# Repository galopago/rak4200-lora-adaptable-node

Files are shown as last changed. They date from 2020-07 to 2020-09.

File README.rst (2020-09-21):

=======================================================================================================================================
RAK4200 based LoRa node, with multiple expansion possibilities and designed to fit inside a generic 83x58x33mm waterproof enclosure box.
=======================================================================================================================================

LoRa node powered by AA batteries ready to install inside an easy to find waterproof enclosure.

Read this in other languages: `Español </docs/README.es.rst>`_

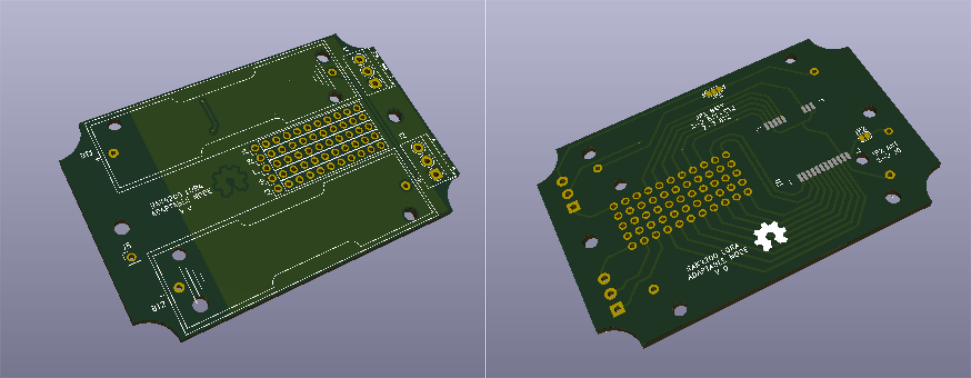
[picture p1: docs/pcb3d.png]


Key features:
-------------
* Powered by 2xAA (1.5v) batteries or a single (3.0v) battery.
* Waterproof if installed in an "easy to find worldwide" 83x58x33mm waterproof plastic enclosure (multiple choices: clear cover, wall mounting tabs, etc.).
* Class A battery powered or Class C external powered via screw terminal.
* RAK4200 = SX1276+STM32L071. So no additional cpu/microcontroller needed for a complete solution.
* Can be programmed using `RAK Unified Interface (RUI) API, <https://doc.rakwireless.com/quick-start/rak5010-wistrio-nb-iot-tracker/rui-online-compiler>`_ for rapid development or STM32 CUBE LoRa stack.
* TH pad for a spring antenna or U.FL connector for external antenna.
* Prototyping/expansion area.

How to use this repository
--------------------------

The PCB was developed in KiCad V5.1, and include some elements from the official repo.

To setup KiCad to use the downloaded library from the repo instead of the stock that came with the installer, `this post <https://forum.kicad.info/t/library-management-in-kicad-version-5/14636>`_ will give you some lights.

Directory structure
-------------------
* The root folder contains KiCad files: project, schematic and PCB.
* library directory (git submodule) contains schematics symbol libraries.
* modules directory (git submodule) contains footprint libraries.
* packages3d directory (git submodule) contains 3D model libraries.
* gerber/single directory contains ready to manufacture files, for a single board.
* gerber/panel_100mmx100mm directory contains ready to manufacture files that fits in a 100mm x 100mm panel (use Vcuts!).

License
-------



This is an Open Hardware project and is licensed under a `Creative Commons Attribution 4.0 International License, <http://creativecommons.org/licenses/by/4.0/>`_

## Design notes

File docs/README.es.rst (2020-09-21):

====================================================================================================================================================
Nodo LoRa basado en RAK4200, con multiples posibilidades de expansion y diseñado para instalarse en una caja a prueba de agua generica de  83x58x33mm 
====================================================================================================================================================

Nodo LoRa alimentado por baterias AA listo para instalar en caja a prueba de agua facil de conseguir.

Lea esto en otros idiomas: `English <../README.rst>`_



Caracteristicas claves:
-----------------------
* Alimentacion mediante 2 baterias AA (1.5v) o mediante una sola bateria de 3.0v en formato LR6.
* A prueba de agua si se instala en una caja plastica "facil de conseguir" de dimensiones 83x58x33mm. Hay varios modelos: tapa transparente, pestañas para montaje en pared, etc.).
* Clase A alimentado mediante baterias o clase C alimentado externamente por el terminal de tornillo.
* RAK4200 = SX1276+STM32L071. No se requiere una cpu o microcontrolador adicional para una solucion completa.
* Puede ser programado usando la API  `RAK Unified Interface (RUI), <https://doc.rakwireless.com/quick-start/rak5010-wistrio-nb-iot-tracker/rui-online-compiler>`_ para desarrollo rapido o mediante STM32 CUBE LoRa.
* Multiples posibilidades para antena: pad para soldar antena de resorte interna o conector U.FL para antena externa
* Area para prototipado y/o expansion.

Como usar este repositorio
--------------------------
El circuito impreso fue desarrollado en KiCad V5.1, e incluye algunos elementos de la biblioteca en el repositorio oficial.

Para configurar KiCad para que use las bibliotecas descargadas del repositorio en vez de usar las que vienen incluidas con el instalador, se recomienda leer el `siguiente articulo <https://forum.kicad.info/t/library-management-in-kicad-version-5/14636>`_ el cual brinda ideas de como hacerlo.

Estructura de directorios
-------------------
* El directorio raiz contiene los archivos de KiCad: proyecto, esquematico y circuito impreso.
* library (submodulo git) contiene las bibliotecas de simbolos esquematicos.
* modules (submodulo git) contiene las bibliotecas de footprints.
* packages3d (submodulo git) contiene las bibliotecas de modelos 3D.
* gerber/single contiene los archivos para fabricacion del circuito impreso, para una sola tarjeta.
* gerber/panel_100mmx100mm contiene los archivos para fabricacion del circuito impreso, para multiples tarjetas que caben en un panel de 100mm x 100mm (usando Vcuts!).

Licencia
-------



Este es un proyecto de Hardware Libre y esta licenciado bajo una licencia `Creative Commons Attribution 4.0 International License, <http://creativecommons.org/licenses/by/4.0/>`_

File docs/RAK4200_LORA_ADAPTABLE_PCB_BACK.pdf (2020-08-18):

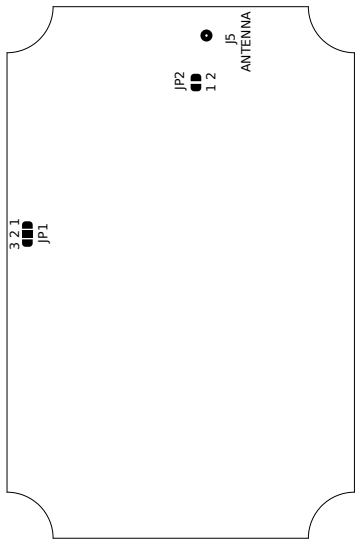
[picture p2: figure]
ANTENNA

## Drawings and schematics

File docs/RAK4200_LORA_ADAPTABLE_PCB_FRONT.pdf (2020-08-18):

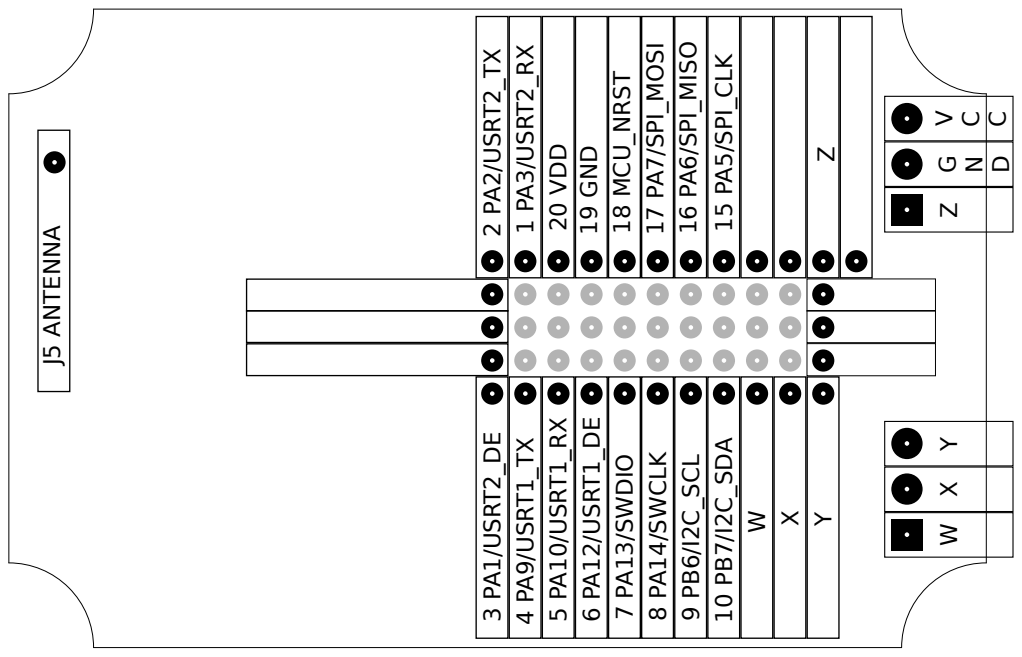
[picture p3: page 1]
3 PA1/USRT2_DE; 4 PA9/USRT1_TX; 5 PA10/USRT1_RX; 6 PA12/USRT1_DE; J5 ANTENNA; 7 PA13/SWDIO; 8 PA14/SWCLK; 9 PB6/I2C_SCL; 10 PB7/I2C_SDA; 2 PA2/USRT2_TX; 1 PA3/USRT2_RX; 20 VDD; 19 GND; 18 MCU_NRST; 17 PA7/SPI_MOSI; 16 PA6/SPI_MISO; 15 PA5/SPI_CLK; Z YXW

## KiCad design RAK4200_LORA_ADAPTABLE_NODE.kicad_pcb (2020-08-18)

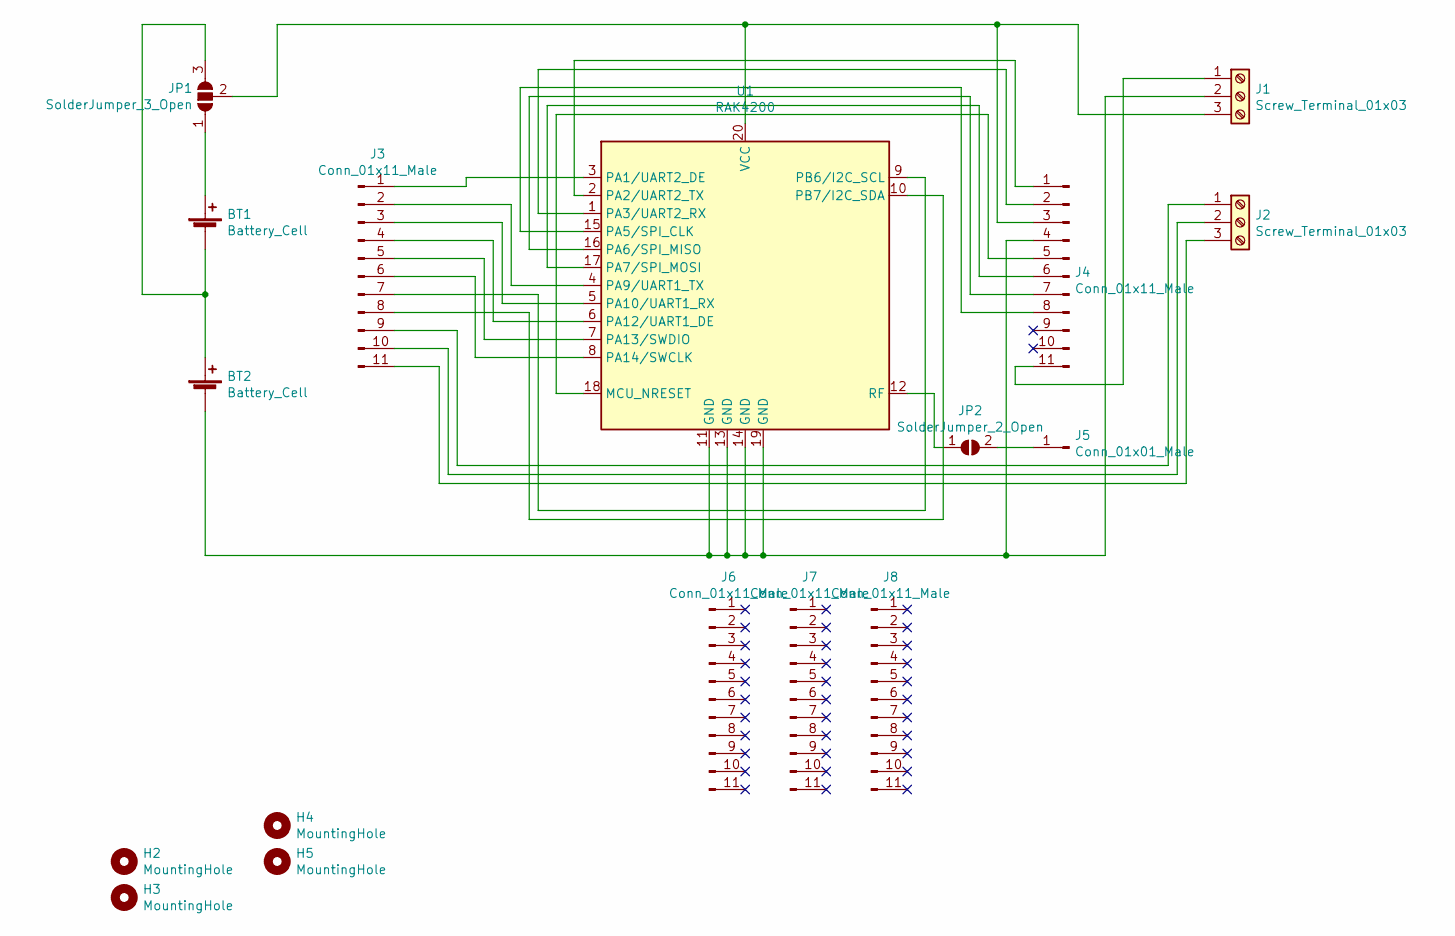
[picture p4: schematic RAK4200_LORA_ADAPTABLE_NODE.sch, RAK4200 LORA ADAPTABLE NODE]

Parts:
BT1, BT2: Battery_Cell; BatteryHolder_Keystone_2460_1xAA
H2, H3, H4, H5: MountingHole; MountingHole_3mm
J1, J2: Screw_Terminal_01x03; TerminalBlock_4Ucon_1x03_P3.50mm_Horizontal
J3, J4, J6, J7, J8: Conn_01x11_Male; PinHeader_1x11_P2.54mm_Vertical
J5: Conn_01x01_Male; PinHeader_1x01_P2.54mm_Vertical
JP1: SolderJumper_3_Open; SolderJumper-3_P1.3mm_Open_RoundedPad1.0x1.5mm_NumberLabels
JP2: SolderJumper_2_Open; SolderJumper-2_P1.3mm_Open_RoundedPad1.0x1.5mm
U1: RAK4200

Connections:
unnamed: BT1.1 (+), JP1.1 (A)
unnamed: BT1.2 (-), BT2.1 (+), JP1.3 (B)
unnamed: BT2.2 (-), J1.2, J4.4, U1.11 (GND), U1.13 (GND), U1.14 (GND), U1.19 (GND)
unnamed: J1.1, J4.11
unnamed: J1.3, J4.3, JP1.2 (C), U1.20 (VCC)
unnamed: J2.1, J3.9
unnamed: J2.2, J3.10
unnamed: J2.3, J3.11
unnamed: J3.1, U1.3 (PA1/UART2_DE)
unnamed: J3.2, U1.4 (PA9/UART1_TX)
unnamed: J3.3, U1.5 (PA10/UART1_RX)
unnamed: J3.4, U1.6 (PA12/UART1_DE)
unnamed: J3.5, U1.7 (PA13/SWDIO)
unnamed: J3.6, U1.8 (PA14/SWCLK)
unnamed: J3.7, U1.9 (PB6/I2C_SCL)
unnamed: J3.8, U1.10 (PB7/I2C_SDA)
unnamed: J4.1, U1.2 (PA2/UART2_TX)
unnamed: J4.2, U1.1 (PA3/UART2_RX)
unnamed: J4.5, U1.18 (MCU_NRESET)
unnamed: J4.6, U1.17 (PA7/SPI_MOSI)
unnamed: J4.7, U1.16 (PA6/SPI_MISO)
unnamed: J4.8, U1.15 (PA5/SPI_CLK)
unnamed: J5.1, JP2.2 (B)
unnamed: JP2.1 (A), U1.12 (RF)

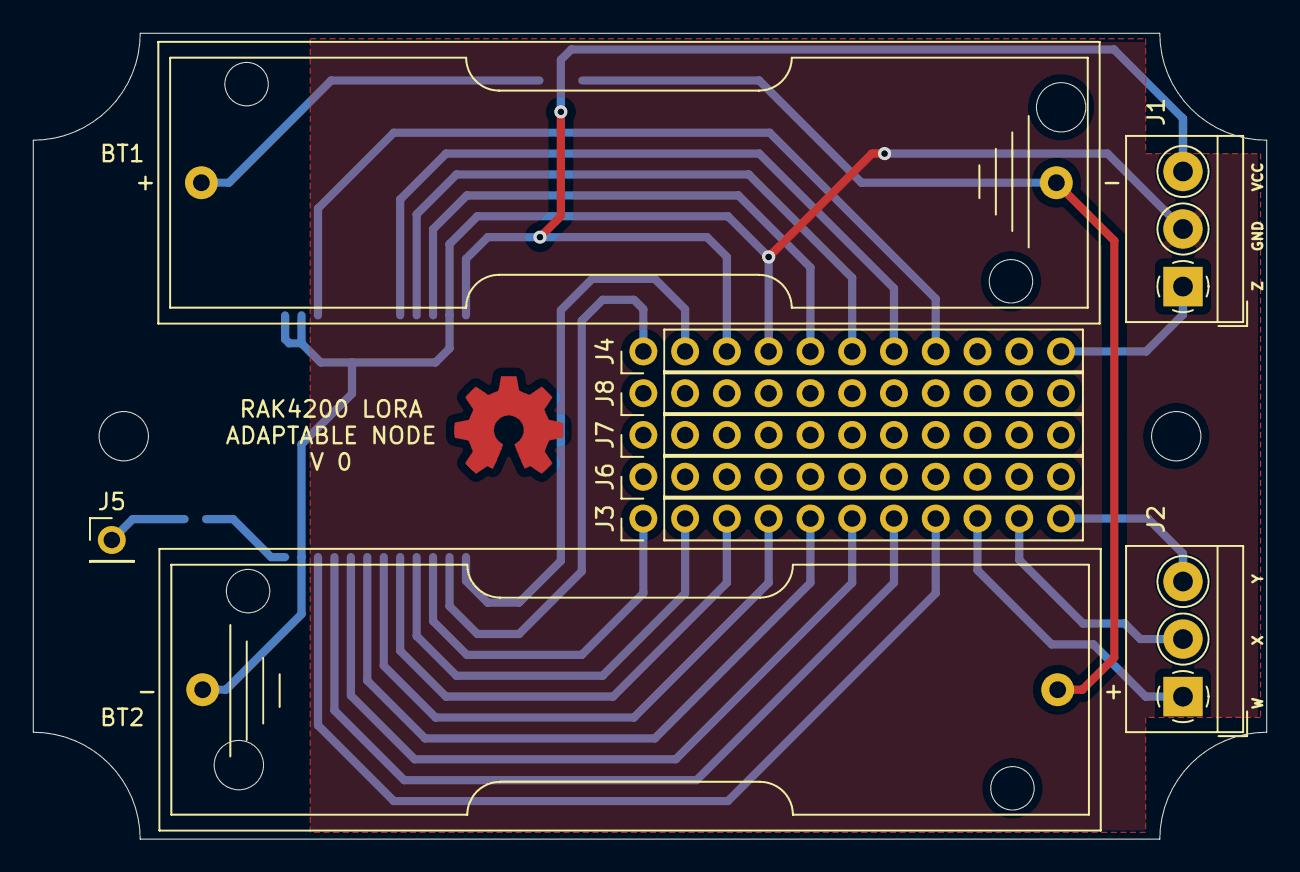
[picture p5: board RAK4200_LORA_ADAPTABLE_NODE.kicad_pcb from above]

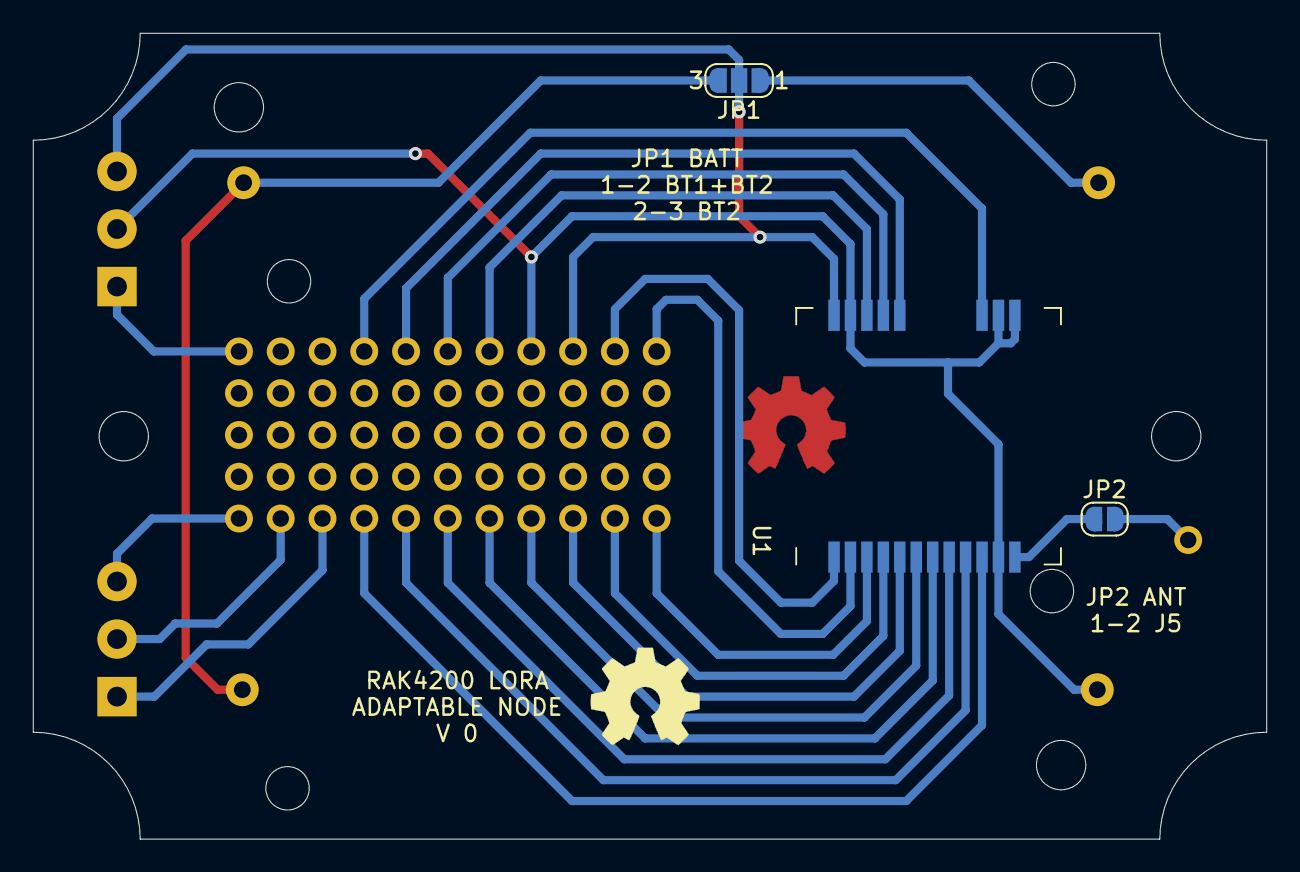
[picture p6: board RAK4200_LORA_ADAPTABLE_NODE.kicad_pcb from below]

Board: 2 copper layers, 75.0 x 49.0 mm, 17 parts (3 on the bottom side), 24 nets.

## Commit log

2020-07-23 battery holder, solder jumper and screw terminal added
    [RAK4200_LORA_ADAPTABLE_NODE.kicad_pcb, RAK4200_LORA_ADAPTABLE_NODE.sch]
2020-07-24 expansion connectors added
    [RAK4200_LORA_ADAPTABLE_NODE.kicad_pcb, RAK4200_LORA_ADAPTABLE_NODE.sch]
2020-07-24 all I/O already connected
    [RAK4200_LORA_ADAPTABLE_NODE.kicad_pcb, RAK4200_LORA_ADAPTABLE_NODE.sch]
2020-07-25 all traces routed
    [RAK4200_LORA_ADAPTABLE_NODE.kicad_pcb, RAK4200_LORA_ADAPTABLE_NODE.sch]
2020-07-25 all silks msg done
    [RAK4200_LORA_ADAPTABLE_NODE.kicad_pcb]
2020-07-25 copper plane - single board gerbers
    [RAK4200_LORA_ADAPTABLE_NODE-B_Cu.gbr, RAK4200_LORA_ADAPTABLE_NODE-B_Mask.gbr, RAK4200_LORA_ADAPTABLE_NODE-B_SilkS.gbr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]
2020-07-25 100mmx100mm panel gerbers
    [RAK4200_LORA_ADAPTABLE_NODE_PANEL-B_Cu.gbr, RAK4200_LORA_ADAPTABLE_NODE_PANEL-B_Mask.gbr, RAK4200_LORA_ADAPTABLE_NODE_PANEL-B_SilkS.gbr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]
2020-07-30 renamed pcb png file
2020-08-18 added pcb pinout info to docs folder
2020-08-18 silkscreen ext ant fix
    [RAK4200_LORA_ADAPTABLE_NODE.kicad_pcb]

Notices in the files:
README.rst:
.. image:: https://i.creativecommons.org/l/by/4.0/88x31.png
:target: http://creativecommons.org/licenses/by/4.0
